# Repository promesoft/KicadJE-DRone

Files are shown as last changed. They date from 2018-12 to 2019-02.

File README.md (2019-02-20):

# Kicad-droneosc
This is a very simple circuit based around S9018 NPN BJT's.

It creates a saw pulse and in this config I can modulate them via the base of the BJT. Its inspired by the work of [Kerry Wong](http://www.kerrywong.com/2014/03/19/bjt-in-reverse-avalanche-mode/) and [Sam Battle](https://www.lookmumnocomputer.com/projects/#/simplest-oscillator/)

## Reverse Avalanche Breakdown
As this oscilator is based on reverse avalanche breakdown it is highly dependent on the type of BJT used. For this setup the SS9018 high frequency transistor has been selected as it start oscilating below 9V (which is often used in stomp box effect pedals). 
For more details on this oscilator visit [AN47](https://www.analog.com/media/en/technical-documentation/application-notes/an47fa.pdf)

## Status - Rev A board - initial verification
### Initial 
| Stage  | Detail | Status |
| --- | --- | --- |
| create material  | sch/pcb | produced Rev A  |
| | gerber | produced and uploaded RevA |
| production  | ordered  | OK |
|  | produced | OK |
|  | delivered | OK |
### Preliminary validation
| Test  | Detail | Status |
| --- | --- | --- |
| Initial Inspection | Visual | See Errata |
| | Component Mounting | OK LFO 2|
| Initial Technical Test | LFO 1 |  |
| | OSC 1 |  |
| | LFO 2 | OK |
| | OSC 1 |  |

### Secondary validation
| Test  | Detail | Status |
| --- | --- |--- |
| Product Test | LFO 1 |  |
| | OSC 1 |  |
| | LFO 2  | OSC+AM OK - Volume ok (see Errata)|
| | OSC 1 |  |
| Physical | 1590 II Box |  |
|  | Eurorack |  |
| Long Term Product Test | | ongoing |
### Errata
 - Footprint of mini jacks should be updated
 - Assisting text on potmeters
 - D1 is 0805 - should have been SOD123 or Minimelf
 - RV7 Volume Pot is reversed (possibly all other vol pots)
 - 10uf used for LFO output capacitor
  
### Issues and Notes

## Physical Construction
 - 50,8x100,2mm
 - Optional cut in 2 
 - Mounting in either Eurorack or Stompbox 1590B

## Vital Components
 - Jack connectors: PJ-321 (important for the footprint)
 - SS9018 HJ NPN BJT for the oscillator (important for the voltage)
 - 5516 LDR for the vactrol (matched with the pot for the osc)

## Features
4 Separate saw oscillators.
 - 2 identical
 - 1 simple
 - 1 with VCO (Vactrol) and Modulation input

## Modulation
### AM
Each section of the oscilators are AC coupled with a reasonably high input resistance that in the prototype enabled cascading of the oscilators so the output of the oscilator would be AM mulated with the input on the base.
### CV / FM / Vactrol
Prototype has been performed with a GL5516 LDR in a heat shrink package with an LED - its not exactly 1V/Oct but it works
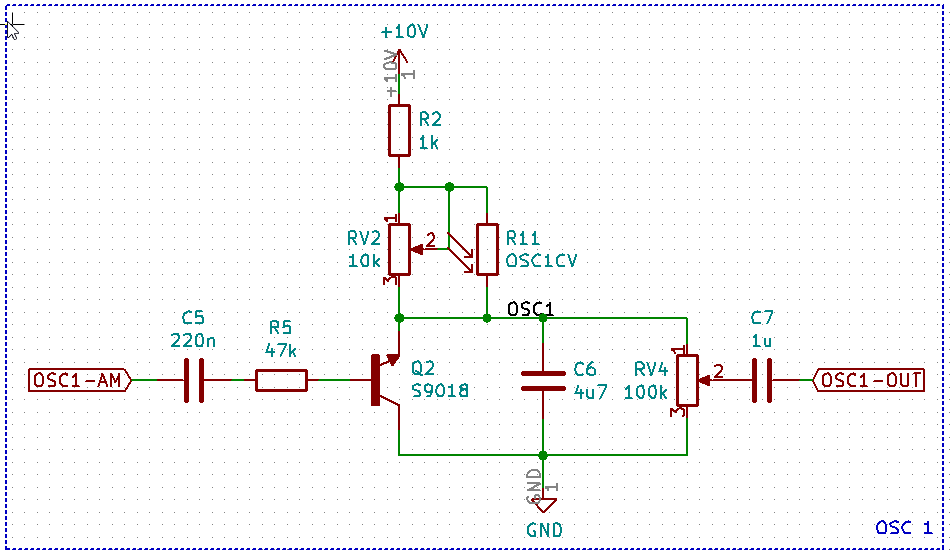
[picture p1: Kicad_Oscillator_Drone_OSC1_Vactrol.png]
Vactrol


# Prototype implementation
A simple stripboard implementation in a 1590B stompbox
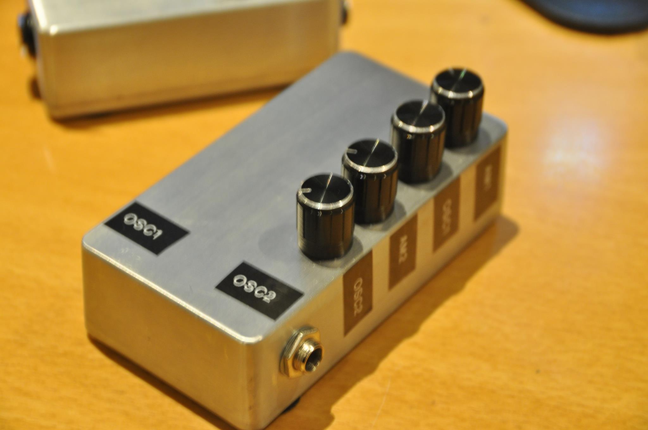
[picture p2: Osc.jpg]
OSC


# 3D 
Visualization of the board
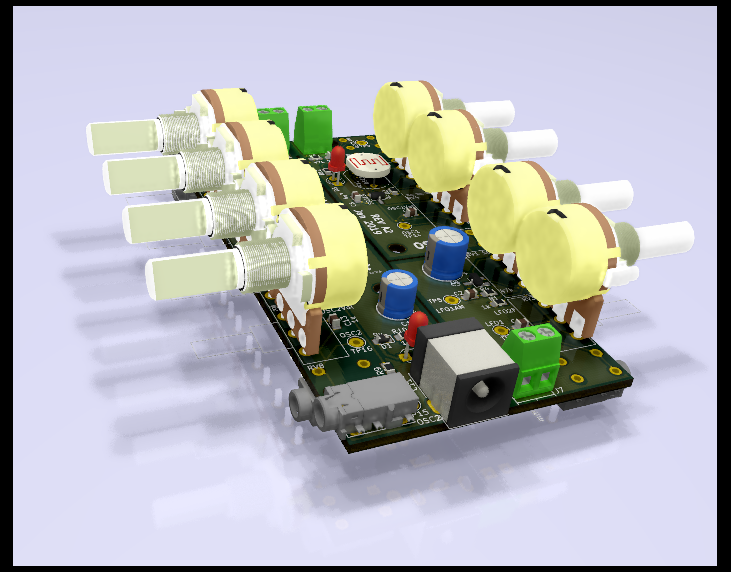
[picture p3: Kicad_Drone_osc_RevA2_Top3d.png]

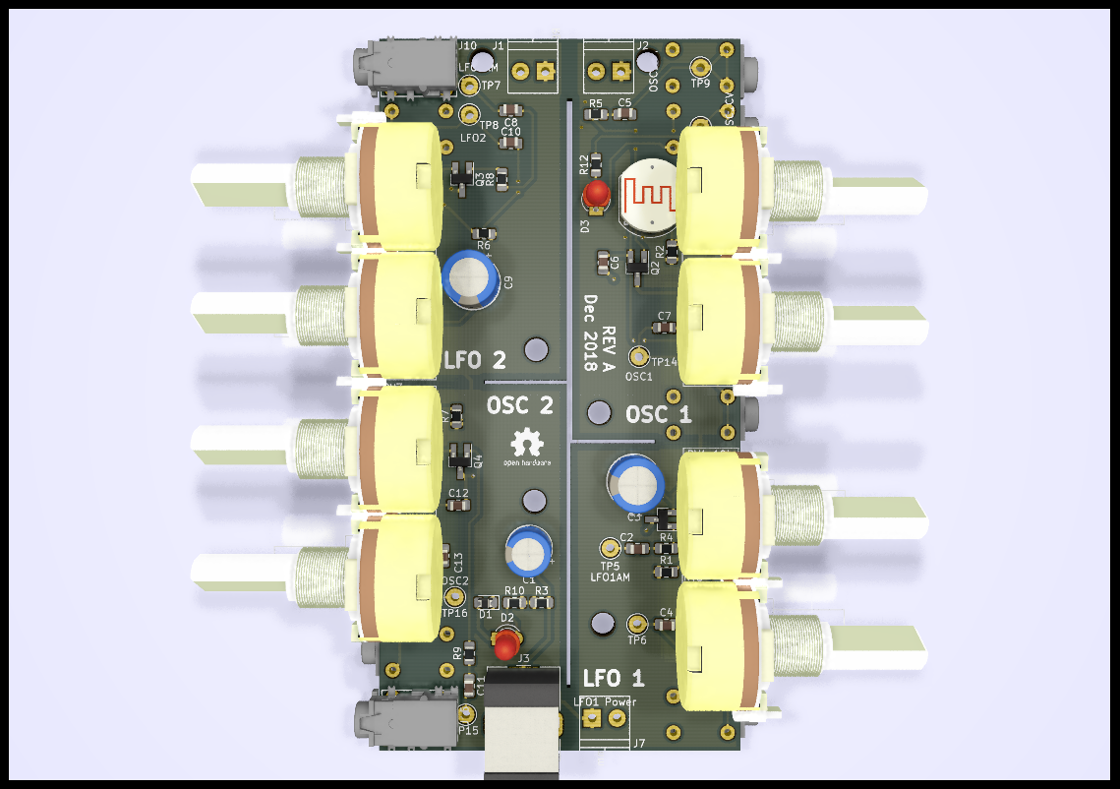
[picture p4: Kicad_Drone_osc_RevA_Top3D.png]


## LFO 1 and OSC 1 3D
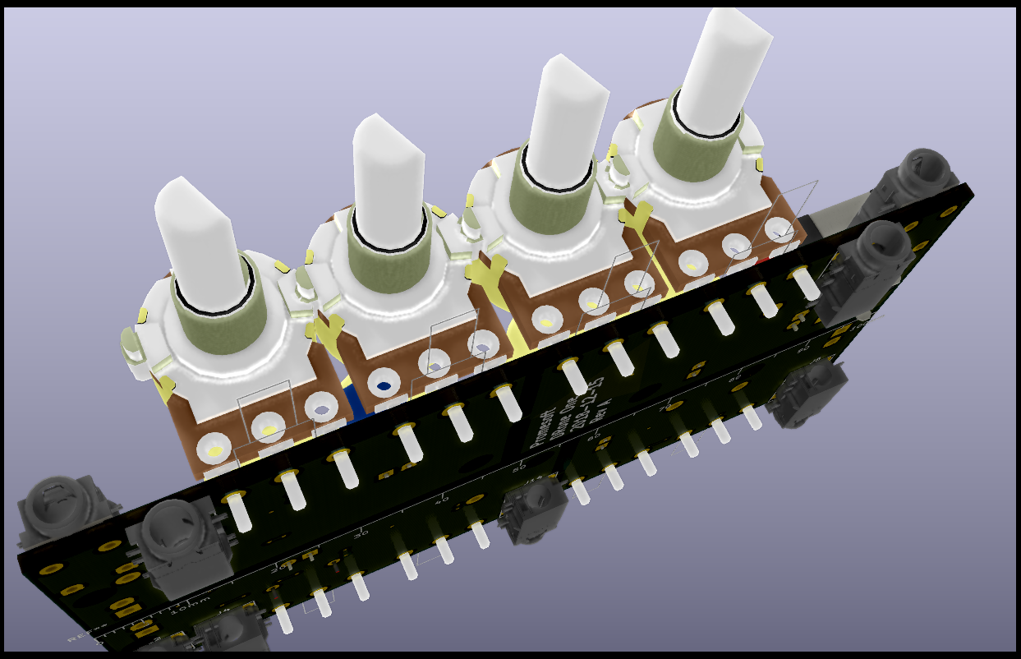
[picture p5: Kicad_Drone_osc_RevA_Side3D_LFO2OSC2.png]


# LFO 1 Schematic
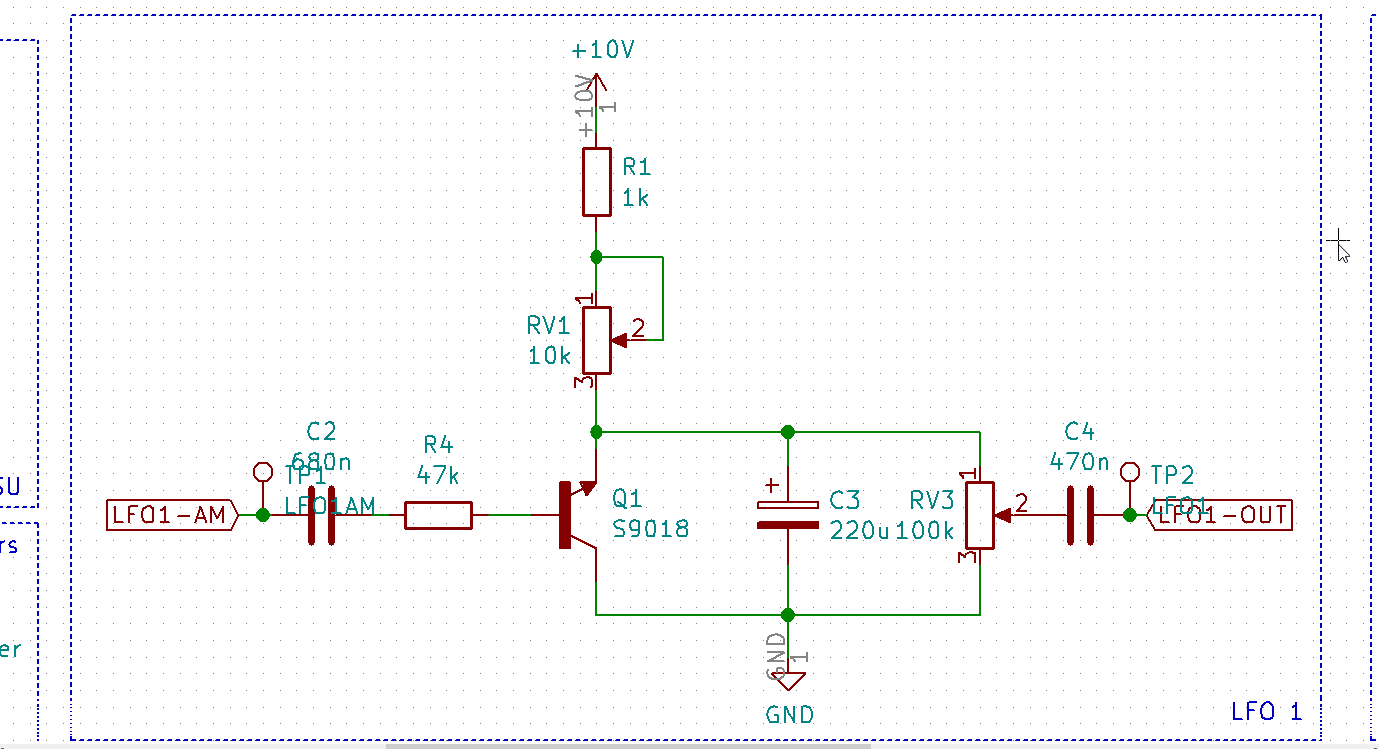
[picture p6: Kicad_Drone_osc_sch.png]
Schematic


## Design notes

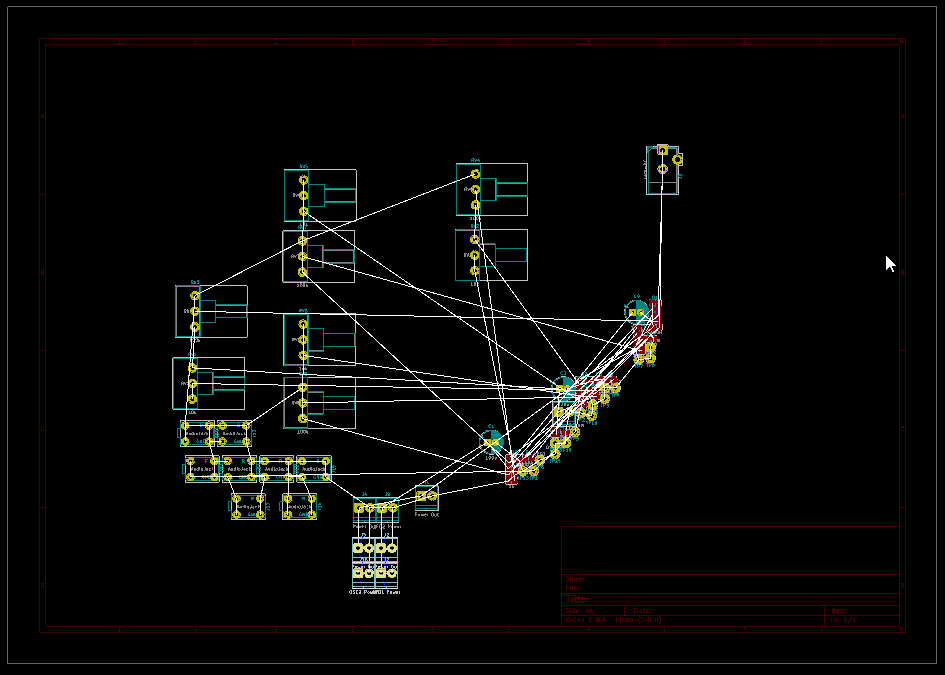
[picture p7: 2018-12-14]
Kicad_Drone_osc.png

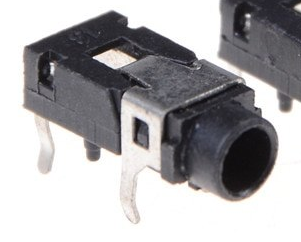
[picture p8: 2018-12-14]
PJ-321.png

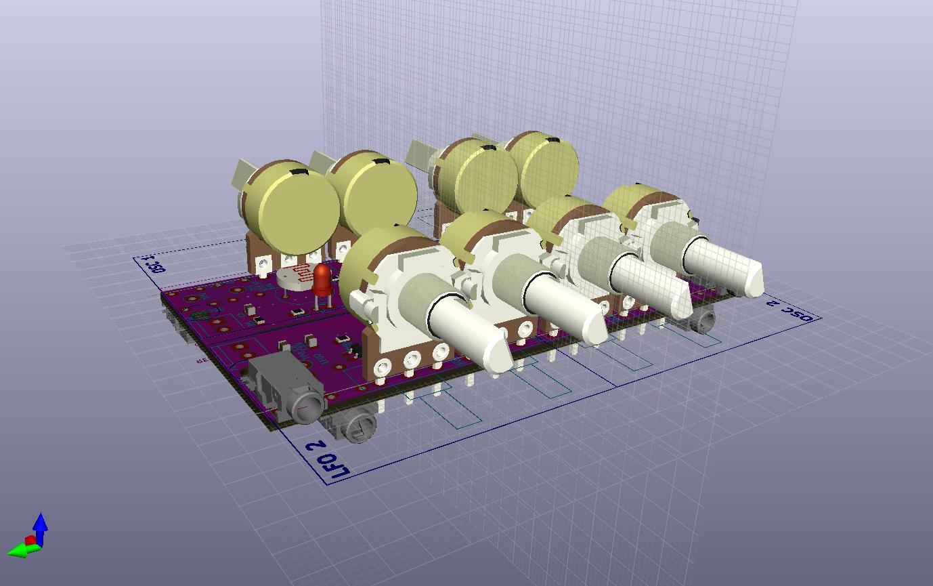
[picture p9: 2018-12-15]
RevA/Kicad_Drone_osc_3d.png

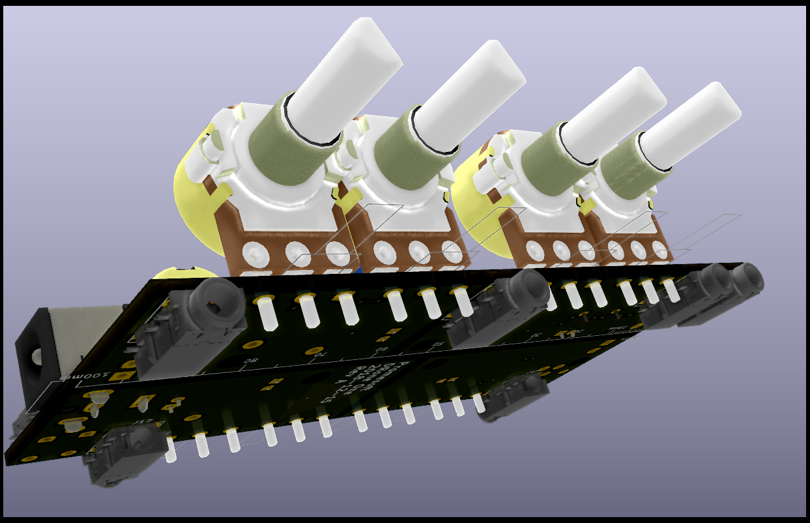
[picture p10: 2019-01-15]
RevA/Kicad_Drone_osc_RevA_Side3D_LFO1OSC1.png

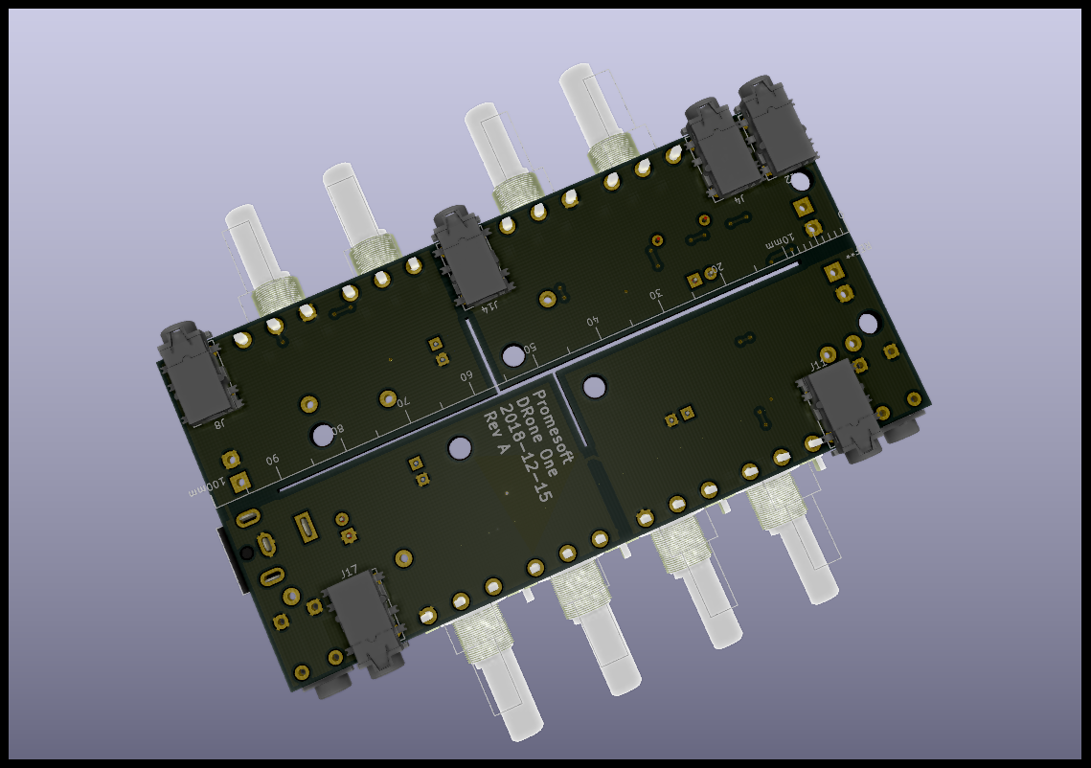
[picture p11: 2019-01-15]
RevA/Kicad_Drone_osc_RevA_Bottom3D.png

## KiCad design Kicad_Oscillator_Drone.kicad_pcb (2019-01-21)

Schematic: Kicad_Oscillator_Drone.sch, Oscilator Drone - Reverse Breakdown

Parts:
C1: 100u; CP_Radial_D6.3mm_P2.50mm
C2, C8: 680n; C_0805_2012Metric_Pad1.15x1.40mm_HandSolder
C3: 220u; CP_Radial_D7.5mm_P2.50mm
C4, C10: 470n; C_0805_2012Metric_Pad1.15x1.40mm_HandSolder
C5, C11: 220n; C_0805_2012Metric_Pad1.15x1.40mm_HandSolder
C6: 4u7; C_0805_2012Metric_Pad1.15x1.40mm_HandSolder
C7, C13: 1u; C_0805_2012Metric_Pad1.15x1.40mm_HandSolder
C9: 100u; CP_Radial_D7.5mm_P2.50mm
C12: 2u2; C_0805_2012Metric_Pad1.15x1.40mm_HandSolder
D1: 9v; D_0805_2012Metric_Pad1.15x1.40mm_HandSolder
D2: red; LED_D3.0mm
D3: OSC1CV; LED_D3.0mm
J1, J2: Power Out; TerminalBlock_Phoenix_PT-3.5mm_2pol
J3: Jack-DC; BarrelJack_CUI_PJ-063AH_Horizontal
J4: OSC1CV; AudioJack3StereoNarrow-PJ-321
J7: LFO1 Power; TerminalBlock_Phoenix_PT-3.5mm_2pol
J8, J10, J11, J12, J14, J15, J17: AudioJack; AudioJack3StereoNarrow-PJ-321
Q1, Q2, Q3, Q4: S9018; SOT-23_Handsoldering
R1, R2, R6, R7: 1k; R_0805_2012Metric_Pad1.15x1.40mm_HandSolder
R3: 680R; R_0805_2012Metric_Pad1.15x1.40mm_HandSolder
R4, R5, R8, R9: 47k; R_0805_2012Metric_Pad1.15x1.40mm_HandSolder
R10, R12: 1k2; R_0805_2012Metric_Pad1.15x1.40mm_HandSolder
R11: OSC1CV; R_LDR_10x8.5mm_P7.6mm_Vertical
RV1, RV2, RV5, RV6: 10k; Potentiometer_Piher_T-16H_Single_Horizontal
RV3, RV4, RV7, RV8: 100k; Potentiometer_Piher_T-16H_Single_Horizontal
TP1: OSC1CV; Pin_D1.0mm_L10.0mm_LooseFit
TP5: LFO1AM; Pin_D1.0mm_L10.0mm_LooseFit
TP6: LFO1; Pin_D1.0mm_L10.0mm_LooseFit
TP7: LFO2AM; Pin_D1.0mm_L10.0mm_LooseFit
TP8: LFO2; Pin_D1.0mm_L10.0mm_LooseFit
TP9: OSC1AM; Pin_D1.0mm_L10.0mm_LooseFit
TP14: OSC1; Pin_D1.0mm_L10.0mm_LooseFit
TP15: OSC2AM; Pin_D1.0mm_L10.0mm_LooseFit
TP16: OSC2; Pin_D1.0mm_L10.0mm_LooseFit

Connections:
+10V: D1.1, J1.1, J2.1, J7.1, R1.1, R2.1, R3.1, R6.1, R7.1, R10.2
/DC_in: C1.1, J3.1, R3.2
/LFO1: C3.1, Q1.2, RV1.3, RV3.1
/LFO2: C9.1, Q3.2, RV5.3, RV7.1
/OSC1: C6.1, Q2.2, R11.2, RV2.3, RV4.1
/OSC1_CV: J4.T, R12.2, TP1.1
/OSC2: C12.1, Q4.2, RV6.3, RV8.1
GND: C1.2, C3.2, C6.2, C9.2, C12.2, D1.2, D2.1, J1.2, J2.2, J3.2, J7.2, J8.R, J8.S, J10.R, J10.S, J11.R, J11.S, J12.R, J12.S, J14.R, J14.S, J15.R, J15.S, J17.R, J17.S, Q1.3, Q2.3, Q3.3, Q4.3, RV3.3, RV4.3, RV7.3, RV8.3
LFO1-AM: C2.2, TP5.1
LFO1-OUT: C4.1, J8.T, TP6.1
LFO2-AM: C8.2, J10.T, TP7.1
LFO2-OUT: C10.1, J11.T, TP8.1
unnamed: C2.1, R4.1
unnamed: C4.2, RV3.2
unnamed: C5.1, R5.1
unnamed: C7.2, RV4.2
unnamed: C8.1, R8.1
unnamed: C10.2, RV7.2
unnamed: C11.1, R9.1
unnamed: C13.2, RV8.2
unnamed: D2.2, R10.1
unnamed: D3.1, J4.R, J4.S
unnamed: D3.2, R12.1
unnamed: Q1.1, R4.2
unnamed: Q2.1, R5.2
unnamed: Q3.1, R8.2
unnamed: Q4.1, R9.2
unnamed: R1.2, RV1.1, RV1.2
unnamed: R6.2, RV5.1, RV5.2
unnamed: R7.2, RV6.1, RV6.2
unnamed: R2.2, R11.1, RV2.1, RV2.2
OSC1-AM: C5.2, J12.T, TP9.1
OSC1-OUT: C7.1, J14.T, TP14.1
OSC2-AM: C11.2, J15.T, TP15.1
OSC2-OUT: C13.1, J17.T, TP16.1

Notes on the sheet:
PSU
OSC 1
OSC 2
LFO 1
LFO 2
Connectors

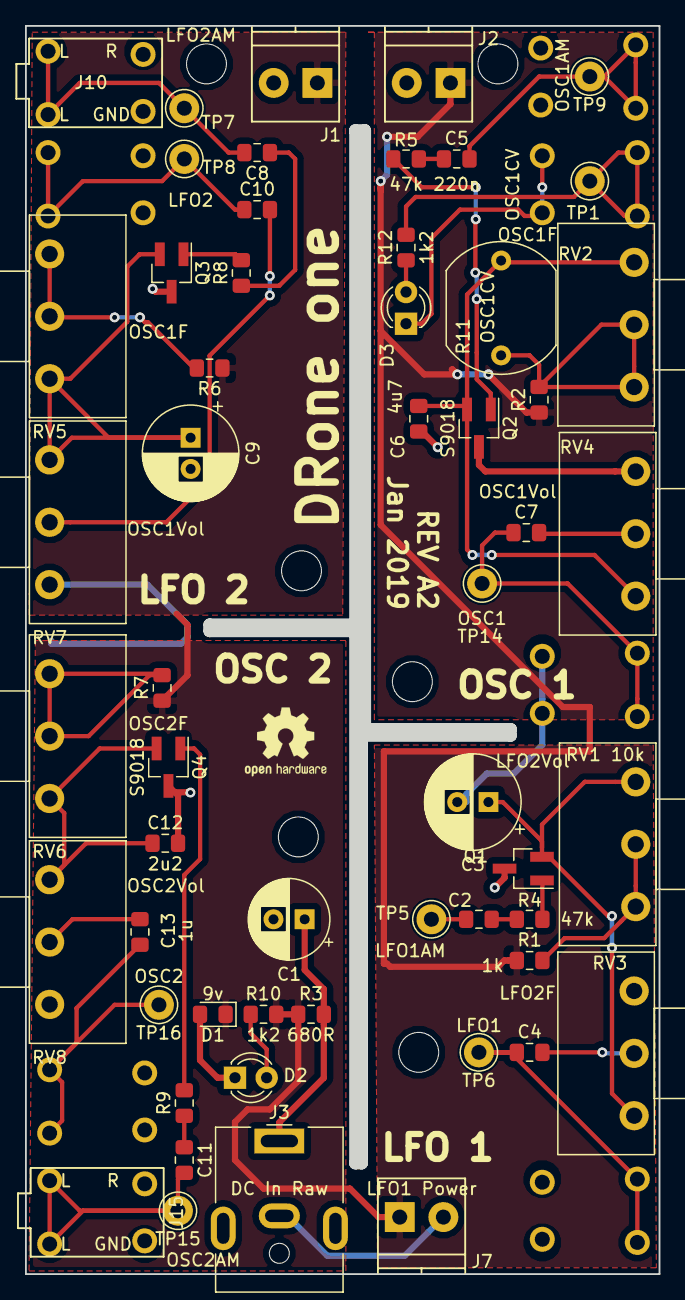
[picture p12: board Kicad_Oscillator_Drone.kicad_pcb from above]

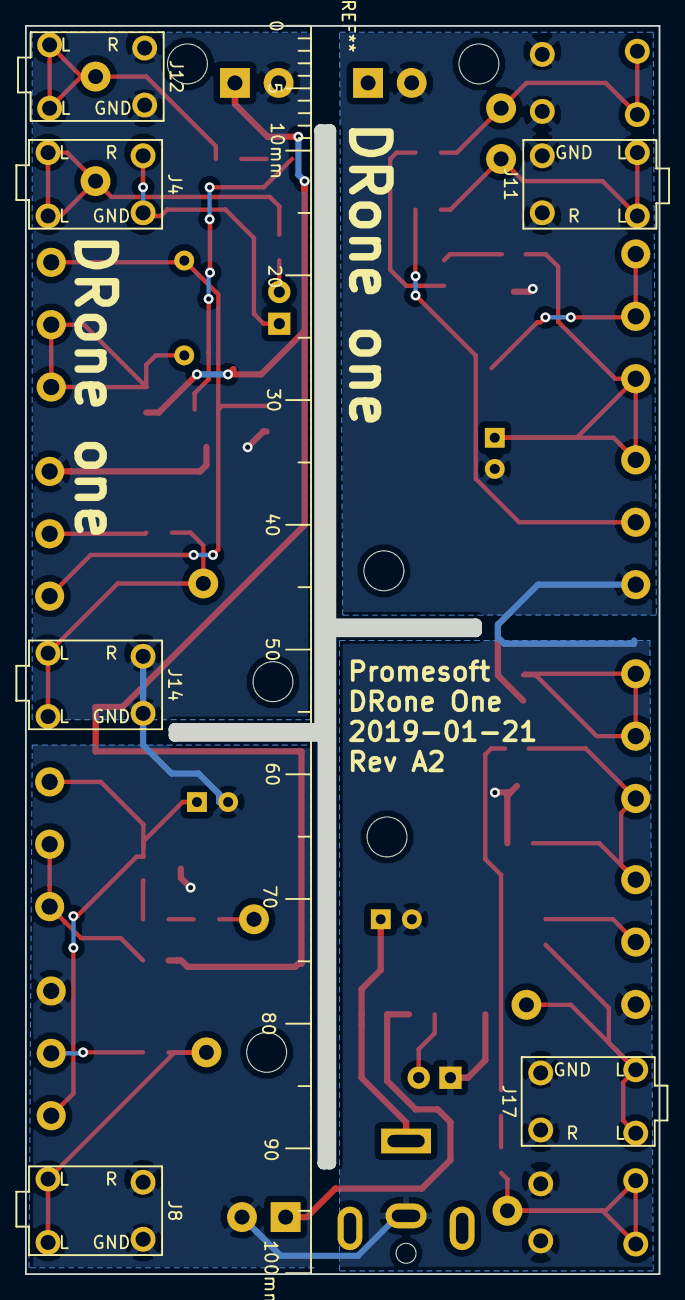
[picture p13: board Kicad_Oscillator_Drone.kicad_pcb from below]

Board: 2 copper layers, 50.8 x 100.1 mm, 61 parts (6 on the bottom side), 35 nets.

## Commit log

2018-12-14 Import Local Project
    Halfway to laying out dual print with an LFO and an OSC on each part of the board
    [Oscillator_Drone.kicad_pcb, Oscillator_Drone.sch]
2018-12-14 prefix
    prefix
    [Kicad_Oscillator_Drone.kicad_pcb, Kicad_Oscillator_Drone.sch]
2018-12-14 Removed connectort
    Connectors and testpoints removed.
2018-12-14 Vactrol and pwr fix
    Power fix and alteration
    Remove LFO1 AM
    Add Vactrol to OSC1
    Net names
    [Kicad_Oscillator_Drone.sch, _saved_Kicad_Oscillator_Drone.sch]
2018-12-15 3D Updated
    3D Models
    [Kicad_Oscillator_Drone.kicad_pcb, Kicad_Oscillator_Drone.sch, _saved_Kicad_Oscillator_Drone.sch]
2018-12-15 Routing started LFO2 OSC1
    [Kicad_Oscillator_Drone.kicad_pcb]
2018-12-15 Rev A done
    Ground planes
    Mounting holes
    DRC
    Labels
    [Kicad_Oscillator_Drone.kicad_pcb]
2018-12-16 Gerber
    Gerber output added for JLC
    [Kicad_Oscillator_Drone-B.Cu.gbr, Kicad_Oscillator_Drone-B.Mask.gbr, Kicad_Oscillator_Drone-B.Paste.gbr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]
2018-12-17 README w Schematic
    update readme
2018-12-25 Vactrol pic
    Vactrol on OSC1
    [Kicad_Oscillator_Drone.sch]
2019-01-21 Rev A2 - Text and Jack footprint update
    [Kicad_Oscillator_Drone.kicad_pcb]
2019-01-21 RevA Cleanup
    [Kicad_Oscillator_Drone-B.Cu.gbr, Kicad_Oscillator_Drone-B.Mask.gbr, Kicad_Oscillator_Drone-B.Paste.gbr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]
